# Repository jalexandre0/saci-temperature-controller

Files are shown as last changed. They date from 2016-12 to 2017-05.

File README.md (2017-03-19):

# SACI Temperature Controller

SACI (Seu Amigo Cervejeiro Inteligente or Your Smart Brew Buddy in a quick translation) is a NODEMCU 1.0 (ESP8266 12-E)
temperature controller for homebrewing and beer fermentation.

SACI was built using inexpensive parts available in any eletronic store (see the BoM and schematics bellow)
and software was writen in C/C++ using arduino/genuino framework, so SACI is easy to build,
and easier to hack.

### Reliable behavior with new brains
If you are a homebrewer, the chances are you already know and relies on ON/OFF controllers (STC-1000 is a world wide example) to ferment your beer. SACI uses the same logic for control temperature and offers new possibilites, like data logging with IoT free services ( MatLab thingspeak.com ), automatic profile, responsive web interface and the chance to write your own plugin or interface.   

### Automatic profile
SACI was built with **set and forget mindset**. You plug it in your fridge, adjust target temperature,
create a profile for the next two weeks and done. You can do other tasks and SACI will evaluate
time using NTP and adjust your target temperature based on your profile.

### Clean and Responsive Web Interface
We don´t like bloated interfaces, so we choose to keep it clean and 100% browser ready.
SACI has an responsive interface, beautiful in any device. Nothing to install, just point
your PC or smartphone to SACI IP address and configure it.

### Over the air updates
Has your SACI laying behind your fridge and you are not in the mood to push it just for a small update?
No problem. SACI has Over The Air enabled at boot, so you can code and update directly from your notebook or desktop.

### Arduino/Genuino IDE Compatible
You already use Arduino/Genuino Framework to write your own code and want write your own plugin using it?
No problem. The code is compatible with Arduino/ESP8266 language and IDE. No additional software required.   

### Easy to build and hack
Anyone armed with soldering wire and a dozen of components can build and modify SACI hardware, and,
because of arduino/genuino framework, everyone can write plugins in a couple of hours.
In fact, SACI already has plugins for MatLab Thingspeak services, influxDB time series database
and a draft for Rsyslog integration (Some work is needed here).

### HTTP POST config and json responses
All the configuration is passed to SACI over URL encoded post, so, if you know how to manipulate this, you are able to create your own interface e/or dashboard to view your brew status.

###Everyone loves MQTT
Just push information to your smartphone or desktop using one of bazillions free MQTT dashboards and public brokers around the internet.

### Plugin Ready
Already have a working code for **<insert your favorite IoT provider here>** and
want to put it in SACI?

Just get your code and put it inside plugins directory and insert your function inside main loop,
and your plugin is ready to work. SACI was sectioned to enclose things to need be enclosed together,
creating a easy to maintain and less fragmented code.

### Built with ESP8266
The chip behind SACI is the well beloved ESP8266 (12E).
NodeMCU in a protoboard or a full production-ready PCB layout with fancy  SMD components.
WeeMos or generic devkit boards, does not matter. Its ESP8266 after all.

# Hardware Build Instructions
### Schematics
Shame on me here!
I don´t have the skills to write eletronic diagrams and schematics for other people, and don´t have time or will to overcome this. To be honest, I barelly can read my own schematics. If you decide to build your own PCB, you will found the etcheable layout, a totally messed up Fritzing file and this JPG file to help you with wiring diagram. Any help to improve this will be over-happily  welcomed. :)

Image of wiring diagram

**PS: Works on 127v or 220v**

### Bill Of Materials
- 1x nodeMCU 1.0 or ESP8266-12E chip/board
- 2x 15 pin female header (single row)
- 2x BC546 NPN Transistors or equivalent
- 2x 1n4148 Zenner Diode  or equivalent
- 2x 5V coil relay (10A) or SSR
- 2x 2 pin screw terminals
- 1x 3 pin screw terminal
- 1x 4.7K resistor (1/4W)
- 1x DS18B20 temperature sensor
- (OPTIONAL) Another DS18B20 for fridge temperature
- 2x power sockets for fridge and heat element
- 1x plastic case of your preference (or none...)
- Materials for soldering, PCB build and wires

# Software Build Instructions
### Dependencies
- [OneWire](https://github.com/PaulStoffregen/OneWire)
- [DallasTemperature](https://github.com/milesburton/Arduino-Temperature-Control-Library)
- [NtpClient](https://github.com/arduino-libraries/NTPClient)
- [PubSubClient](https://github.com/knolleary/pubsubclient)

### PlatformIO
- Clone this repository
- On PlatformIO menu, click on "Open Project Folder" and select repository folder
- On PlatformIO menu, click on "Initialize or Update PlatformIO Project"
- Choose NodeMCU 1.0 and click process
- Update your platformio.ini file as bellow

```
[env:nodemcuv2]
platform = espressif8266
framework = arduino
board = nodemcuv2
build_flags = -Wl,-Tesp8266.flash.4m1m.ld
board_f_cpu = 160000000L
#Platform.io seems to auto detect port in some systems. 
#if not, specify your com port. 
#upload_port = /dev/ttyUSB0
lib_deps =
  OneWire
  DallasTemperature
  NTPClient
  PubSubClient
```

- Create your 'src/config.h' file (use 'src/config.sample.h' as example)
- Enable/Disable desired plugins on config.h
- Build main image and upload
- Build SPIFFS filesystem and upload.
- Find your address using serial monitor
- Access and configure

### Arduino IDE
- Install ESP8266 support as described [here](https://github.com/esp8266/Arduino)
- Install the dependencies using Arduino Library Manager or download and by yourself
- Rename 'saci-temperature-controller/src/main.cpp' to 'src.ino'
- Copy all h and cpp files from plugins folder to src folder
- Open src.ino file
- Create and edit config.h file (use config.sample.h as example)
- Fix path errors on CPP/H files in plugins directory
- Select NodeMCU 1.0 as board
- Select 160Mhz CPU Frequency
- Select Flash Size 4M (3M SPIFFS)
- Select Upload speed 115200
- Build the software
- Deploy firmware and filesystem using OTA ou USB port

### CLI
You can build SACI in any operating system with support to  Python 2.7 and [PlatformIo-Core.](http://docs.platformio.org/en/stable/core.html)
The instructions bellow are tested headless Raspeberry PI with latest raspbian distro.

Check the [docs](http://docs.platformio.org/en/stable/installation.html#installation) if the method bellow do not work for you.

```
$ sudo apt-get install python-pip
  #Fix errors about requests
$ rm -rf /usr/local/lib/python2.7/dist-packages/requests*
$ sudo -i pip install -U platformio
$ git clone https://github.com/jalexandre0/saci-temperature-controller.git
$ cd saci-temperature-controller
$ cp src/config.sample.h /src/config.h
$ vim src/config.h
$ platformio run -t upload
$ platformio run -t uploadfs

```

# Help and todo
- Improve software build instructions
- Write eletronic diagrams that people can read and follow
- Review hardware and schematics to improve safety
- ~~Test any CLI build mode~~
- Fix typos and spelling errors
- Save and load profiles by name
- Fix / Clean up / review code
- Test and write instructions for Farenheit temperature
- Test or port the code for atmel hardware (arduino/genuino based boards)
- Run other algorithms outside the hardware (slave mode)
- Improve HTTP api
- Add continuous integration
- Add unit tests

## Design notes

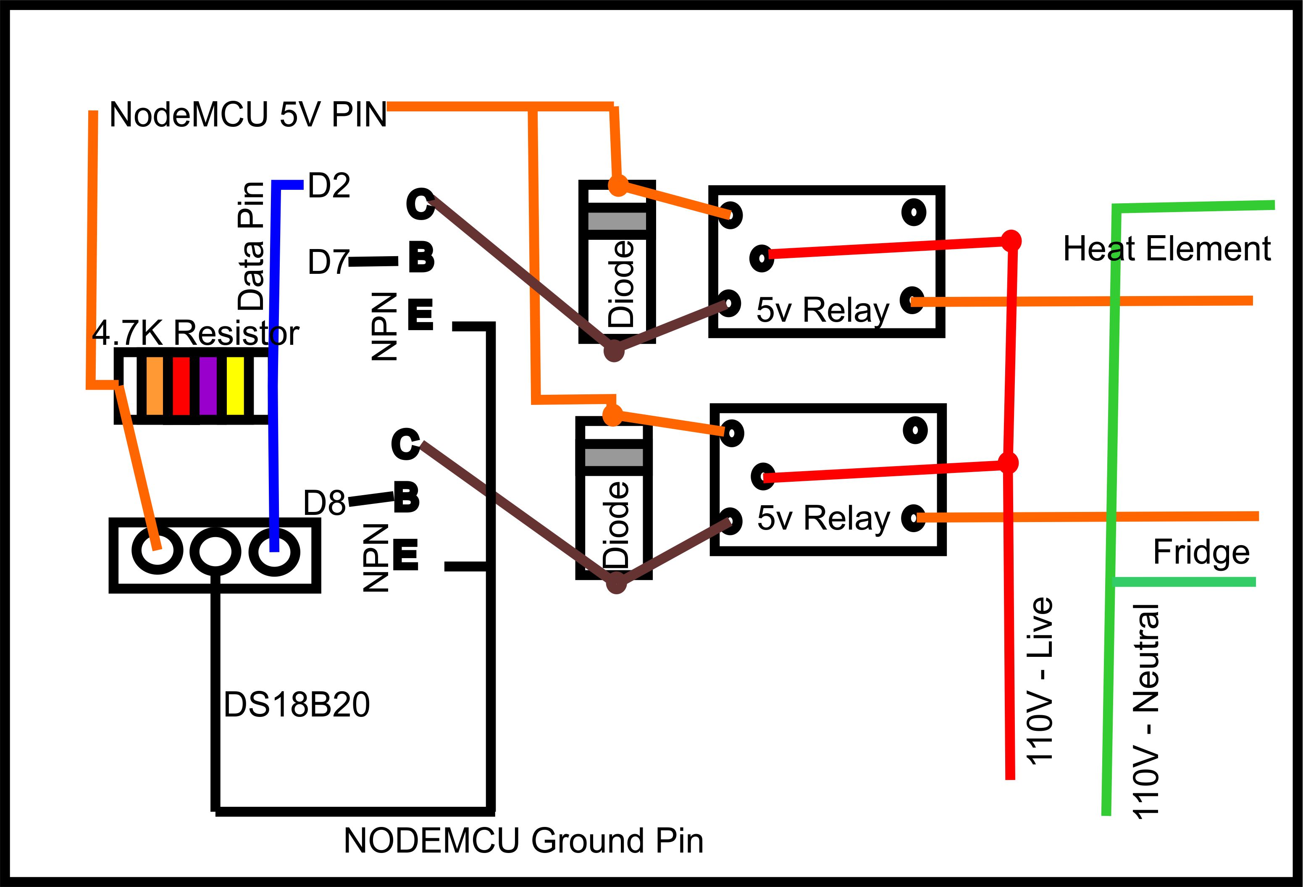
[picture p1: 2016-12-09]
schematics/SACI PCB Diagram.jpg

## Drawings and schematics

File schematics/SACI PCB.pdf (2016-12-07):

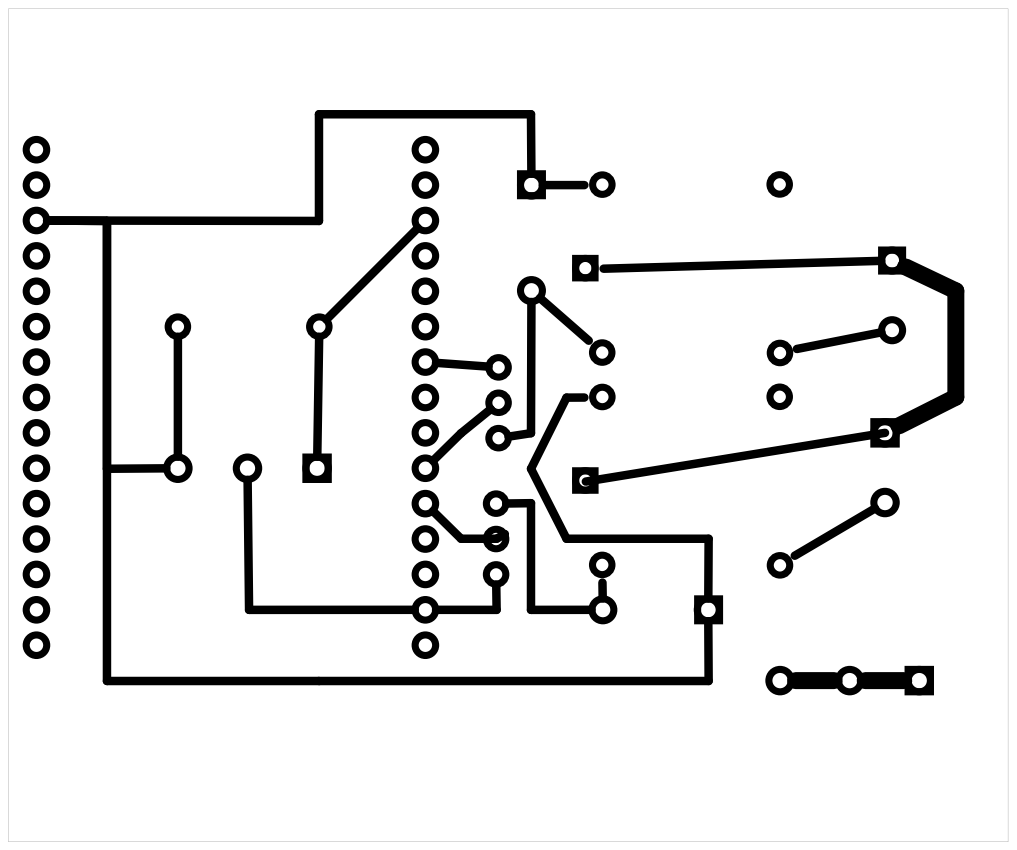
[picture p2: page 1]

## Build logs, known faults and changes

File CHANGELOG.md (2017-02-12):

## [New Release]  2017-02-12

### Changed
- Bug Fix: Fixed a bug where heat and cool can switched on at same time. 

## [New Release]  2017-02-10

### Added
- Low pass filter for smooth sensor readings and ploting
- Possibilities to add a second DS18B20 ( fridgeRead() )
- Sensors are upadted after main loop (faster readings)
- Instructions for CLI compilation

### Changed
- MIT to GPL-V3 License change
- Plugin configuration (and send delays...) are now centralized in config.h
- Moved delays to main.cpp instead plugin files.

### Fixed
-Typos preventing compilation in Unix-Like Systems

## [fix_profile] 2016-12-16

### Fixed
- Fixed issue with ramp profile

### Changed
- Changed output for /status.json and serial

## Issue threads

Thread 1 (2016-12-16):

Ramp Profile won´t work as expected

jalexandre0, 2016-12-16:
Ramp profile is jumping from first to last step.
Investigating right now.

jalexandre0, 2016-12-16:
I guess it is fixed. Let me test this a couple of days, and them I will close this issue.

jalexandre0, 2017-01-02:
Fixed in las commit. :)

Closed 2017-01-02.

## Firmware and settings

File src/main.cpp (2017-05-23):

#include <Arduino.h>
#include <ArduinoOTA.h>
#include "BangController.h"
#include "DS18B20.h"
#include "config.h"
#include "WebInterface.h"
#include <NTPClient.h>
#include <ESP8266WiFi.h>

//Plugins I wrote for myself
#include "plugins/ThingSpeak.h"
#include "plugins/UDPLog.h"
#include "plugins/InfluxDB.h"
#include "plugins/Mqtt.h"


uint8_t heatPin = D7 ;
uint8_t coolPin = D8 ;
//Pins, config and profile path
BangController saci(coolPin, heatPin, "/saci.txt", "saciprofile.txt");

//NTP  for profile
WiFiUDP udpSocket;
NTPClient timeClient(udpSocket, "pool.ntp.br", -10800, 60000);

void setup () {

  /* Watchdog register will wait 8000ms for a signal.
     If signal do not come (ie function loop or hardware fail),
     micro processor will reset itself
  */

  wdt_enable(8000) ;
  Serial.begin(115200) ;

  WiFi.mode(WIFI_STA);
  WiFi.begin(ssid, pass);

  ArduinoOTA.onStart([]() {
    //nothing to do on start
  });

  // Restart after Over The Air update.
  ArduinoOTA.onEnd([]() {
    ESP.restart();
  });

  ArduinoOTA.begin();

  //see DS18B20.h and WebInterface for sensor and interface Init ;
  sensorInit() ;
  interfaceInit() ;

  //NTP update
  timeClient.begin() ;
  timeClient.update() ;

  //load config from file to memory
  saci.loadConfig() ;

  if (mqttPlugin) {
    mqttInit() ;
  }
}

void loop() {
  static uint32_t mqttLastSend ;
  static uint32_t thingSpeakLastSend ;
  static uint32_t influxdbLastSend ;
  uint32_t now = millis()  / 1000 ;

  //main controller action
  saci.run() ;

  //fix_profile debug
  if(WL_CONNECTED && WiFi.localIP().toString() != "0.0.0.0") {
    if ( timeClient.update() ) {
        uint32_t now = timeClient.getEpochTime() ;
        if(saci.getProfileRun() == 1 && now > saci.getLastRamp() + 86400 ) {
          saci.runProfile(now) ;
        }
      }
    }

  //Web interface handler
  interface.handleClient() ;

  // OTA handler
  ArduinoOTA.handle() ;

  //My Plugins (enable or disable adjusting "config.h")
  if (mqttPlugin) {
    //receiver subscribed topics
    mqttLoop() ;

    //sender
    if (now > mqttLastSend + mqttDelay ) {
      mqttLastSend = now ;
      mqttPublish() ;
    }
  }

  if (influxdbPlugin && now > influxdbLastSend + influxdbDelay ) {
    influxdbLastSend = now ;
    influxSend() ;
  }

  if (thingSpeakPlugin && now > thingSpeakLastSend + thingSpeakDelay ) {
    thingSpeakLastSend = now ;
    thingSpeakSend() ;
  }

  //Serial Output: Usefull for some debug
  Serial.println(saci.getConfig()) ;
  Serial.println(" ");

  //Prepare sensors for the next read
  sensorRequest() ;

  wdt_reset() ;

}

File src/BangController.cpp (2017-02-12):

#include "BangController.h"
#include <Arduino.h>
#include <FS.h>
#include <ESP8266WiFi.h>
#include "DS18B20.h"


BangController::BangController(uint8_t _coolPin, uint8_t _heatPin, \
                               String _configFile,String  _profileFile) {
  configFile = _configFile;
  profileFile = _profileFile;
  coolPin = _coolPin ;
  heatPin = _heatPin ;
  pinMode(coolPin, OUTPUT) ;
  pinMode(heatPin, OUTPUT) ;
  digitalWrite(coolPin, LOW) ;
  digitalWrite(heatPin, LOW) ;
  SPIFFS.begin();
}

BangController::~BangController() {
  //nothing to destruct
}

void BangController::heat(bool _status) {
  if( _status ) {
    digitalWrite(coolPin, LOW) ;
    digitalWrite(heatPin, HIGH) ;
    status = 1 ;
  }
  else {
    digitalWrite(heatPin, LOW) ;
    lastHeat = (millis() / 1000) ;
    status = 0 ;
  }
}

void BangController::cool(bool _status) {
  if ( _status ) {
    digitalWrite(heatPin, LOW) ;
    digitalWrite(coolPin, HIGH) ;
    status = 2 ;
  }
  else {
    digitalWrite(coolPin, LOW) ;
    lastCool = (millis() / 1000);
    status = 0 ;
  }
}

String BangController::getConfig() {
  String jsonOutput =  "{\"id\":" ;
  jsonOutput += ESP.getChipId() ;
  jsonOutput += "," ;
  jsonOutput += "\"address\":" ;
  jsonOutput += "\"" ;
  jsonOutput += WiFi.localIP().toString();
  jsonOutput += "\"" ;
  jsonOutput += "," ;
  jsonOutput += "\"uptime\":";
  jsonOutput += millis() / 1000;
  jsonOutput += "," ;
  jsonOutput += "\"mode\":" ;
  jsonOutput += "\"" ;
  jsonOutput += mode;
  jsonOutput += "\"";
  jsonOutput += "," ;
  jsonOutput += "\"status\":" ;
  jsonOutput += "\"" ;
  jsonOutput += status;
  jsonOutput += "\"";
  jsonOutput += "," ;
  jsonOutput += "\"beer temperature\":" ;
  jsonOutput += beerTemp();
  jsonOutput += "," ;
  jsonOutput += "\"fridge temperature\":" ;
  jsonOutput += fridgeTemp();
  jsonOutput += "," ;
  jsonOutput += "\"target temperature\":" ;
  jsonOutput += targetTemp ;
  jsonOutput += "," ;
  jsonOutput += "\"heat differential\":" ;
  jsonOutput += heatDiff ;
  jsonOutput += "," ;
  jsonOutput += "\"cool differential\":" ;
  jsonOutput += coolDiff ;
  jsonOutput += ",";
  jsonOutput += "\"heat timer\":" ;
  jsonOutput += heatTimer ;
  jsonOutput +=  "," ;
  jsonOutput += "\"fridge timer\":" ;
  jsonOutput += coolTimer ;
  jsonOutput += "," ;
  jsonOutput += "\"heat trigger\":" ;
  jsonOutput += targetTemp + heatDiff ;
  jsonOutput += "," ;
  jsonOutput += "\"cool trigger\":" ;
  jsonOutput += targetTemp - coolDiff ;
  jsonOutput += "," ;
  jsonOutput += "\"lastRamp\":" ;
  jsonOutput += lastRamp ;
  jsonOutput += "," ;
  jsonOutput += "\"EpochTime=\":" ;
  jsonOutput += timeClient.getEpochTime() ;
  jsonOutput += "," ;
  jsonOutput += "\"ControlStep=\":" ;
  jsonOutput += controlStep ;
  jsonOutput += "}" ;
  return jsonOutput ;
}

void BangController::run() {


  float _maxHeat = targetTemp + heatDiff ;
  float _maxCool = targetTemp - coolDiff ;

  //Mode 0 == Off
  if (mode == 0) {
    BangController::heat(false) ;
    BangController::cool(false) ;
    return ;
  }

  //Mode 1 == AUTOMATIC
  if (mode == 1) {
    //Starting heat if temp is too cool and heat is off
    if ( beerTemp() <= _maxCool && status != 1 ) {
      if ((millis() / 1000) >= ( lastHeat + heatTimer)) {
        BangController::heat(true) ;
        return ;
      }
    }

    //Starting cool if temp is too hot and cool is off
    if ( beerTemp() >= _maxHeat && status != 2 ) {
      if ((millis() / 1000) >= (lastCool + coolTimer)) {
        BangController::cool(true) ;
        return ;
      }
    }

    //Stop heating if setpoint is reached
    if ( beerTemp() >= targetTemp && status == 1 ) {
      BangController::heat(false) ;
      return ;
    }

    //Stop cooling if setpoint is reached
    if ( beerTemp() <= targetTemp && status == 2 ) {
      BangController::cool(false) ;
      return ;
    }
  }

  //Mode 2 == Only Heating
  if (mode == 2) {
    if ( beerTemp() <= _maxCool && status != 1 ) {
      if ( (millis() / 1000 ) >= lastHeat + heatTimer ) {
        BangController::heat(true) ;
        return ;
      }
    }

    if ( beerTemp() >= targetTemp && status == 1 ) {
      BangController::heat(false) ;
      return ;
    }
  }

  //Mode 3 == Only Cooling
  if (mode == 3) {
    if ( beerTemp() >= _maxHeat && status != 2 ) {
      if ( (millis() / 1000 ) >= lastCool + coolTimer ) {
        BangController::cool(true) ;
        return ;
      }
    }


    if (  beerTemp() <= targetTemp && status == 2 ) {
      BangController::cool(false) ;
      return ;
    }
  }
}

//Adjust individual configs
void BangController::setConfig(String _key, String _value)  {

  if (_key == "mode") {
    if (_value == "OFF") {
      mode = 0;
    }

    if (_value == "Automatic") {
      mode = 1;
    }

    if (_value == "Heating") {
      mode = 2;
    }

    if (_value == "Cooling") {
      mode = 3;
    }
  }

  if (_key == "heatTimer") {
   heatTimer = _value.toInt() ;
  }

  if (_key == "coolTimer") {
    coolTimer = _value.toInt() ;
  }

  if (_key == "heatDiff") {
    heatDiff = _value.toFloat() ;
  }

  if (_key == "coolDiff") {
    coolDiff = _value.toFloat();
  }

  if (_key == "targetTemp") {
    targetTemp = _value.toFloat() ;
  }
}

//Save all configs to file
void BangController::writeConfig() {
  String _config ;
  _config +=  "mode=" ;
  _config +=  mode ;
  _config +=  '\n' ;
  _config +=  "heatTimer=" ;
  _config +=  heatTimer ;
  _config +=  '\n' ;
  _config +=  "coolTimer=" ;
  _config +=  coolTimer ;
  _config +=  '\n' ;
  _config +=  "coolDiff=" ;
  _config +=  coolDiff ;
  _config +=  '\n';
  _config +=  "heatDiff=" ;
  _config +=  heatDiff ;
  _config +=  '\n' ;
  _config +=  "targetTemp=" ;
  _config +=  targetTemp ;
  _config +=  '\n' ;
  _config +=  "lastRamp=" ;
  _config += lastRamp ;
  _config +=  '\n' ;
  _config += "controlStep=" ;
  _config += controlStep ;
  _config +=  '\n' ;
  _config += "profileRun=" ;
  _config += profileRun ;
  _config +=  '\n' ;


  File _file = SPIFFS.open(configFile, "w") ;
    _file.print(_config);
    _file.close() ;
}
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

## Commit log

2016-12-07 Initial release
    Working release, can be considered master
    [Saci Fermentation Control - V2.fzz]
2016-12-07 Improve Arduino IDE section on readme
2016-12-09 Fix wiring diagram
    Fixed the image for wiring diagram as pointed by SandroRibeiro at
    homebrewtalk.com.br SACI thread.
2016-12-13 Update readme.md
    Added info about resistor.
2016-12-17 New attempt to fix ramp profile jump
    [main.cpp]
2016-12-17 Add a better output to influxDB to help find the nasty ramp profile bug.
    [BangController.cpp, main.cpp]
2016-12-18 More debug changes to debug and fix profile
    [BangController.cpp, main.cpp]
2017-02-03 Filtering sensor reading for smooth graphs.
2017-02-05 Low pass filter for temperature readings.
2017-02-07 Fix some typos for case sensitive operating systems
    [main.cpp]
2017-02-10 Implemented MQTT, moved plugin timers to main.cpp, put delay config inside config.h
2017-02-12 Bug Fix preventing heat and cool at same time
    [BangController.cpp]
2017-02-13 Fix cooling/heating mqtt status ; Fix step counter
2017-05-11 Update main.cpp
    Fix the call to BangController constructor. The pin´s parameter was changed.
    [main.cpp]
